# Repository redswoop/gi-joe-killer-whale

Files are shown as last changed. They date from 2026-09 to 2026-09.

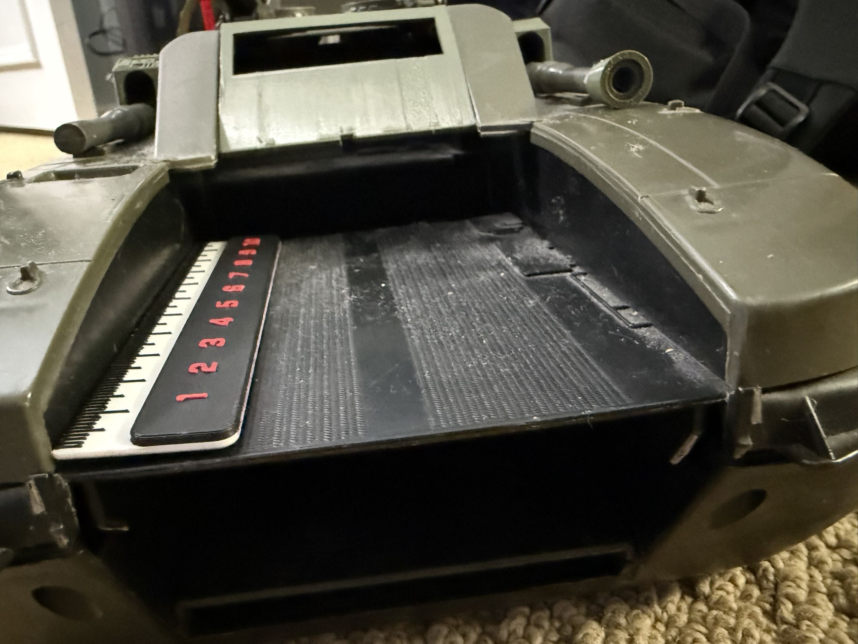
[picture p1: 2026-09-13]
hatch/ref/hull_photo_3.jpeg

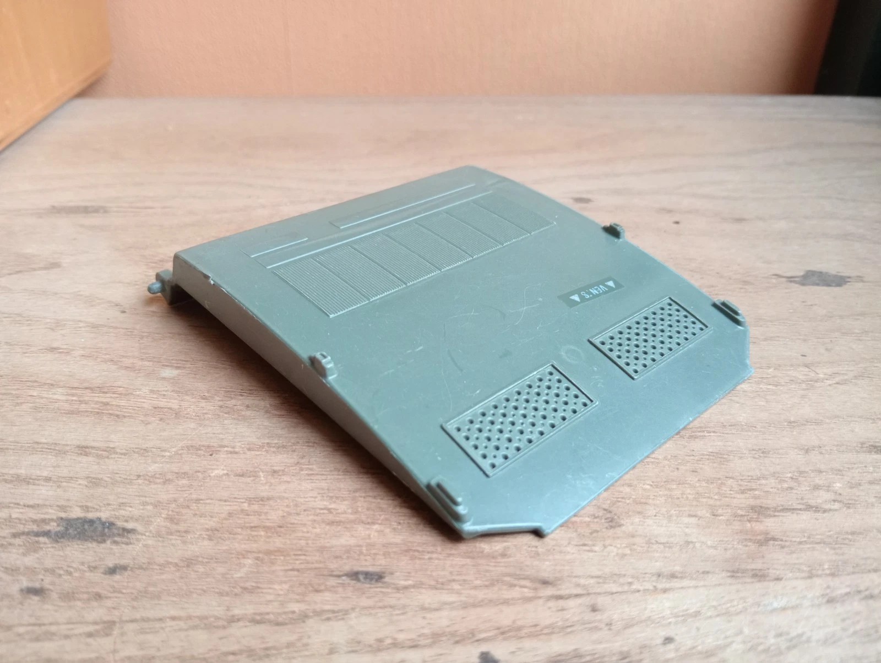
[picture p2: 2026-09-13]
hatch/ref/ebay_three_quarter.jpeg

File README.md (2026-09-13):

# Killer W.H.A.L.E. (1984 G.I. Joe hovercraft) replacement parts

Open-source (MIT) OpenSCAD replacement parts for the 1984 G.I. Joe Killer W.H.A.L.E. hovercraft.
On Makerworld: [cannon covers](https://makerworld.com/en/models/690907-gi-joe-killer-whale-cannon-covers); fan shroud listing in progress (`shroud/MAKERWORLD.md`).

## Building
Needs OpenSCAD 2025+ (Manifold backend). Shared helpers live in [`lib/`](lib/README.md) (a vendored copy of the
workbench's `scad/lib/`). Each assembly's `export.sh` regenerates its `stl/`; `print_layout.scad -D part="..."`
gives one part in its print pose; `check.scad` runs the collision pairs. Everything else below is workbench
convention (the viewer and `tools/` are not part of this repo).

## Layout
One folder for the whole toy, one subfolder per assembly. Each assembly has its own `.scad`,
`viewer.json`, coupons, checks, export script and README, so the viewer previews and rebuilds
them separately. The toy is one git repo (this folder).

| Assembly | Folder | State |
|---|---|---|
| Fan shroud + steering vanes | [`shroud/`](shroud/README.md) | Printed and fitted; fused shroud variant is current. |
| Front landing hatch (bow ramp) + hinge | [`hatch/`](hatch/README.md) | Three parts since 2026-09-13: tray with a dovetail socket, flat front plate with the pins, two glue-on brackets. Coupon (dovetail + pin fits) ready, nothing printed yet. Profile still the 3-point circle. |

Viewer: `cd ../viewer && bun run dev` (once), then http://127.0.0.1:5180/whale/shroud/ or
http://127.0.0.1:5180/whale/hatch/. Tools and shared modules are two levels up:
`use <../../lib/shape.scad>`, `../../tools/check.sh check.scad 'pose=..'`.

Reference material outside this repo: `../../WHALE/` (measurements, the small top-hatch 3mf),
`../../GI Joe/` (downloaded Thingiverse parts), `../GI_Joe_Killer_Whale_Blade.stl` (old fan mesh off the web).

Adding an assembly: `../tools/new-model.sh whale/<name>` copies the template into a new subfolder
(it does not run `git init` inside an existing repo).

History: `shroud/` was the `scad/whale/` repo until 2026-09-12; `hatch/` was a separate `scad/whale_hatch/`
repo, merged in with `git subtree add` so its commits are here too.

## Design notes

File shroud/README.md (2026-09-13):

# Killer W.H.A.L.E. fan shroud + steering vanes (OpenSCAD)

State as of 2026-09-12. Parametric port of Armen's Shapr3D shroud, plus a new print-in-place
vane mechanism reconstructed from photos of the real MET-b52 parts.

## Files
| File | What |
|---|---|
| `shroud.scad` | The whole model. Parameters at the top, one section per Shapr3D operation, then the vane mechanism. |
| `shroud_makerworld.scad` | **MakerWorld customizer build**: one self-contained file (lib inlined, `part` dropdown, curated parameters on top, the rest under `[Hidden]`), because the Parametric Model Maker takes a single file and runs OpenSCAD 2021.01. GENERATED by `build_makerworld.py` from `shroud.scad` + `print_layout.scad` + `../lib/`: re-run it after any change, then re-upload the file on MakerWorld. Verified 2026-09-13: every part renders with the same volume, area and bbox as `print_layout.scad` (zero voxel diff). |
| `viewer.json` | Part list for the browser viewer (`../../viewer`, `bun run dev`, open http://127.0.0.1:5180/whale/shroud/). |
| `print_layout.scad` | `-D part="..."`: each part in its printing pose. Vanes stand on their -Y end (`vane_pose = "vertical"`). With `-D 'vane_mount="fused"'`: `shroud` carries the root bars, `fin_right` / `fin_left` are the plates alone (`fin_print = "edge"`: upside down on the long outer edge, knuckles up; `"vertical"`: on the -Y end), `slat` has its axle barrel on the bed. |
| `hinge_coupon.scad` | Tolerance test print: hinge x3 (standing, pins vertical; `-D 'hinge_pin="filament"'` ladders the filament hole 0.10 / 0.15 / 0.20 instead), slat axle holes x3, keyhole eyes x3, strut pockets x3 + one ear, fork darts x3 (standing) + a piece of rim. |
| `saddle_coupon.scad` | Fit test for the saddle-mount alternative: three rim pieces with receivers at `chan_clrs` = 0.05 / 0.10 / 0.15, plus a standing stub of the bar's -Y end with the wedge peg. |
| `tab_coupon.scad` | Tab fit test print: four 108° arcs of the shroud (30 % of the ring, centred on the tab, `keep = 0.3`) with tab `variants` = [grip, stem_extra] pairs, labelled on a tag. Round 1 laddered the grip; round 2 ladders the stem width at grip 0.7. |
| `check.scad` | Collision pairs (`-D pair="..."`, `steer`, `tilt`, `strut_dz`), including `fan-duct`, `fan-strut`, `fan-roots`, `shaft-strut`. Run them all: `../../tools/check.sh check.scad 'steer=0' 'steer=30' 'steer=-30 tilt=20' 'strut_dz=8'`. Every argument is a pose, so the fused table is `'vane_mount="fused"' 'vane_mount="fused" steer=30' ...` (there `roots-duct` is skipped: one body by design). |
| `compare.scad` | Volume diff against the Shapr3D export (`ref_bodies/` = the STL split per shell). Numeric version: `../../tools/voxcmp.py stl/shroud.stl ref_bodies/shroud.stl`. |
| `export.sh` | Regenerates every STL in `stl/` in parallel. Plain names are the defaults; `_saddle`, `_filpin` and `_saddle_filpin` are the alternates, `_fused` is the fused variant (`shroud_fused`, `fin_right_fused`, `fin_left_fused`, `slat_fused`), plus `saddle_coupon.stl` and `hinge_coupon_filpin.stl`. Run after changing parameters. |
| `render.sh` | Headless PNGs into `renders/`. |
| `Shroud.shapr/.step/.stl` | Armen's originals. Read the .shapr with `../../tools/shapr_dump.py Shroud.shapr`. |

Generic helpers (`rounded_pad`, `wall_blend`, `arc_sweep`, `arc_pts`, `stroke_2d`, `grooves_2d`, `teardrop_2d`, `keyhole_2d`) moved to `../../lib/` on 2026-09-09; STL output was hash-identical before and after.

## Fixed 2026-09-13
`tooth_clr_eff` / `tooth_lead_eff` were assigned (in the fused block) before `tooth_clr` / `tooth_lead` existed, so in the
`teeth` variant the fork dart's slot clearance and lead chamfer were undef since 2026-09-12 (warnings "unknown variable
tooth_clr"). Moved after the tooth block; `export.sh` re-run. The re-exported teeth vane STLs have the same volume, area and
bbox as before (only the triangulation moved), so the undef never reached the printed geometry.
Note: `tie_bar.stl` is exported in `teeth` mode; in `fused` mode the hinge line (and with it the bar's pins) sits 0.2 higher,
which only translates the printed bar, so the file is the same shape either way.

## Coordinate frame
Z = duct axis (airflow exits +Z). Y = the toy's vertical, **+Y (tab side) = the toy's bottom**. X = port/starboard.

## Parts and how they go together
1. **Shroud** (`shroud.stl`, base down, no supports). Has: tooth notches in the rim for the vanes, pocket bosses in the bore at 3/9 o'clock for the strut.
2. **Strut / hub bar** (`strut.stl`, prints standing on one ear, brim, no supports). From the base side, line the ears up with the two pockets and push the bar in until the ears hit the pocket ceilings. The Whale's hull holds it there.
3. **Vanes** (`vane_right.stl`, `vane_left.stl`, standing on the -Y end, 99 mm tall, brim; the dart's underside may want a little support). Armen's call (2026-09-11): vertical prints the ribbed panels as wall detail and puts the hinge pins vertical. Print-in-place hinge: free each plate by working it back and forth. The +Y peg drops through the rim slot into the slot in the Whale's base; the -Y fork dart pushes down over the rim: key into the round notch, prongs straddling the wall, nub clicks.
4. **Slats** (`slat.stl` x2, flat). Spring the 59 mm rods into the holes in the two bars before the vanes go into the shroud. The plate now nearly spans the bars (0.3 mm end gaps), so they stay put sideways.
5. **Tie bar** (`tie_bar.stl`, knurl up). Bulbs go through the big keyholes, slide the bar aft, pins click into the working holes.
6. **Fan** (`fan.stl`, flat, no supports) and **shaft** (`shaft.stl`, lying on its D flat). Push the shaft's plain end into the
   blind D socket under the fan's hub; the tab end goes down through the strut's bore into the hull's push-button gearbox.

Print the **coupon** first and put the winning numbers into `hinge_clr`, `slat_clr`, `tooth_clr` (settled: 0.10, round 3, 2026-09-12), `tie_eye_clr`, `ear_clr`.

## Print next (as of 2026-09-12)
0. **Fan + shaft** (new, unprinted): `stl/fan.stl` (80 mm, flat) and `stl/shaft.stl` (75.5 mm, on its flat). Check the socket fit
   (`shaft_clr`), which way the gearbox turns (`blade_hand`), and how much longer the shaft must be (`shaft_extra`).
0. **Fused variant** (Armen's idea, 2026-09-12, see below): `stl/shroud_fused.stl` (now with the canoes; base down, 36 mm tall; the two bars bridge the bore
   about 20 mm up, so enable supports under them: support PLA, 0 interface distance, as the vane reprint used), `stl/fin_right_fused.stl` +
   `stl/fin_left_fused.stl` (standing on the long outer edge, knuckles up, no support), `stl/slat_fused.stl` x2 (flat), `stl/tie_bar.stl`, plus 2 x 15 mm and
   2 x 61 mm of 1.75 filament. Nothing of it has been printed yet.
0. Filament hinge settled (`fil_clr = 0.15`) and fork dart settled (`tooth_clr = 0.10`): the vanes can print now as
   `vane_right_filpin.stl` + `vane_left_filpin.stl` (fork mount), or `_saddle_filpin` if the saddle wins below.
0. `stl/saddle_coupon.stl` (103 x 39 mm, flat, no supports; the stub wants a brim): decide fork vs saddle. If saddle: put the
   winning cheek clearance into `chan_clr`, then print `shroud_saddle.stl` and `vane_*_saddle.stl` instead of the fork files.
1. `stl/hinge_coupon.stl` (89 x 109 mm): hinge 0.15 / 0.20 / 0.25, slat holes 0.10 / 0.15 / 0.20, fork teeth 0.10 / 0.15 / 0.20 on a piece of rim, strut ear pockets 0.10 / 0.20 / 0.30, keyhole eyes, bullet pins.
2. `stl/shroud.stl`: settled tab, strut pockets, and the new shallow (3 mm) key notches.
3. `stl/strut.stl` (ears in pockets, standing on an ear, brim) once the pocket clearance is known.
4. Vanes and slats once the coupon confirms `hinge_clr`, `tooth_clr` and `slat_clr`.

## Fan and shaft (2026-09-12)
Replaces `../../GI_Joe_Killer_Whale_Blade.stl`, an old mesh off the web that prints badly (thin twisted blades that are all
overhang, a 3.5 mm shaft 65 mm long printed on end). Measured from that mesh: 3 blades, tip r 42.6, blades about 5.7 mm
deep along the axis and pitched roughly 16 deg at mid-span with a straight radial edge and a curved swept edge, a 3.5 mm
shaft tapering to 2.7, and a 1.6 x 1.2 x 0.6 tab on its tip. Armen: the hull has a push-button spin mechanism with (he
thinks) a gear with a slot the tab goes into; the tab engages but the shaft is too short; it should be two parts so the
shaft can print horizontally.
- **Fan** (`fan()`, prints flat, hub bottom on the bed, no supports): hub `fan_hub_d` 10 x `fan_hub_h` 7 with a blind
  D socket `socket_depth` 5.5 deep from the bottom; `fan_n` 3 blades as lofted polyhedra (`blade()`). **Planform** (Armen: 'a smooth swoopy
  spline as their edge ... built between 2 smooth splines'): each edge is a cubic Bezier in a unit frame (1 = `fan_r`;
  `blade_te_c`, `blade_le_c` inner control points), both arriving at `blade_tip` along `blade_tip_dir` from opposite
  sides so the tip is a smooth round of size `blade_tip_k` (0.06: sharp and swept; 0.18 was a fat paddle). **Root**
  (Armen: 'they should end inside of the hub, with the edge fully in contact with the hub ... extrude from a projected
  profile on the hub'): both edges start ON the hub circle, +-`blade_root_a` about the blade's axis so the root chord
  (`blade_root_c` 0.15) is a chord of the hub, and that section is extruded straight inward `blade_bury` 1.5 before the
  Bezier stations begin; the root cap stays 2.5 from the axis, clear of the socket. **Section** (`blade_profile()`):
  flat bottom on the bed, a full round nose of diameter `blade_t` 1.0 at the leading edge, the top on a cosine from
  there up to the trailing edge's thickness, blade_t + chord x tan `blade_pitch` 12 deg capped at `blade_t_max` 2.2
  (the uncapped wedge hit 3.6 at the root: 'very fat, very stubby'; so the real slope is about 6 deg inboard and the
  full 12 outboard of mid-span), rounds `blade_r_top` 0.6 / `blade_r_bot` 0.3 on the trailing corners, all shrinking
  with the chord toward the tip. Nothing overhangs beyond the 0.3 bottom round and no edge is sharp. Lofted over
  `blade_nr` 40 stations to an apex at the tip. The console echoes the reach and the scale. `blade_hand` mirrors the blade once we know which way the gearbox turns.
  **Tip radius**: the strut's pocket bosses reach in to r 40.6, so the reference's 42.6 does not fit this shroud;
  `fan_r = boss_r_in - fan_tip_clr` = 37.6 (`fan_tip_clr` 3, Armen: 'end about 3mm from the mounting boxes'); the outline is scaled (`blade_S()`, a fixed point since the root sits on the hub circle) so its farthest point lands exactly there. The fan sits `fan_gap` 0.5 above the strut's hub core (`fan_z0` 3).
- **Shaft** (`shaft()`, prints lying on its flat): D section, `shaft_d` 3.5 (the reference's; the strut's bore is 5)
  with a `shaft_flat` 0.5 flat, which is the bed face and keys the torque into the hub's D socket (`shaft_clr` 0.10
  per side, untested). `shaft_len` = socket depth + `shaft_reach` 65 (the reference) + `shaft_extra` (0: Armen says
  the reference is too short, number TBD). **Gearbox end** (Armen got the gear out, 2026-09-12: 13-ish teeth, about 14 mm, a
  boss with a socket whose walls slope and whose floor has a keyed slot): the shaft's end is a BLADE that keys into the
  slot, `tab_w` 2.8 x `tab_t` 1.2 x `tab_len` 3.0 (guessed from the photos; **the first print fit the gear**, 2026-09-12; the mesh's
  1.6 x 1.2 x 0.6 pin was a guess), end corners rounded `tab_end_r`, and the shoulders where the round shank becomes the blade are
  convex rounded ramps `tab_ramp` 2.0 long in both directions, which seat on the socket's slopes ('the shaft should have
  rounded ramps to meet with the ramps in the socket'). Like a screwdriver tip ground from round bar; `shaft_tip()` is
  the intersection of the two side-view profiles, the shank cylinder and the D prism. Lying on the flat, the blade's
  underside is 0.65 off the bed for 3 mm: printable.
- Collision pairs `fan-duct`, `fan-strut`, `fan-roots`, `shaft-strut` all clear (teeth and fused, strut seated and
  pulled down 8). Renders: `renders/fan_iso.png`, `fan_top.png`, `fan_close.png`, `fan_hub.png`, `fan_asm.png`, `fan_on_strut.png`, `shaft_print.png`, `shaft_tip.png`, `shaft_tip_under.png`;
  `renders/fan_planforms.png` compares four outline candidates (A first spline, B scimitar, C paddle, D hook).
- Not modelled: any bearing between the hub and the strut (the reference had a 30 mm disc under the blades that may
  have ridden on the strut's ring), the gearbox end of the shaft beyond the tab.

## Fused variant: bars part of the shroud (2026-09-12)
`vane_mount = "fused"` (the default `"teeth"` is everything above; `-D 'vane_mount="fused"'` or the viewer panel).
Armen: "what if I just combined the shroud and the vane roots? That would give me a single, strong shape". So:
- **Root bars are part of the shroud.** Each bar stands on a `post()` at both wall crossings: the bar's own slab from
  `post_bury` (2) below the rim top up into the bar, trimmed to the wall's annulus at every height so it grows straight
  out of the wall with no overhang (the sketch pegs' boxes are longer than the oblique crossing and their corners
  would hang over the bore and past the outer face), with a `post_fillet` (1 mm) concave foot where the bar's faces
  meet the rim. No notches, teeth, receivers, pegs or darts: `vane_slots()`, `tooth_fork()`, `peg()`, `peg2()`,
  `receiver()` are all off. The +Y crossing keeps the same silhouette inside the wall as the sketch peg did in its notch.
- **Canoes on the fused shroud** (`fused_canoes = true`, 2026-09-12: "I don't see an STL with the fully composed shroud
  with the vane roots and canoes"): the posts stay the structure, and over them go the same fairings the loose vanes have:
  the -Y dart (`tooth_fork(-1)`), the +Y pod with its bore-side half-canoe (`peg_pod()`) and the +Y flare above the rim
  (`peg_flare()`, the peg's fillets without the peg's box, whose corners would hang over the bore). In fused mode the
  dart's slot clearance is `tooth_clr_eff = -0.2`, i.e. the prongs sink 0.2 into the wall, and the mouth chamfer is off:
  faces that only touch left the union with open edges and stray shells; sunk, `shroud_fused.stl` is one watertight shell.
  `-D fused_canoes=false` gives the bare posts.
- **Plates are separate parts** on the filament hinge (`hinge_pin` is forced to `"filament"` via `hinge_pin_eff`):
  drop the plate's middle knuckle between the root's two, push 15 mm of 1.75 through, trim 1 mm proud, mushroom.
  The root's holes print lying down in the shroud, so they are teardrops with the roof up (`fil_hole(roof = 1)`).
  **The plate prints standing on its long outer edge, upside down, knuckles up** (`fin_print = "edge"`; Armen's
  print experiments 2026-09-12: the best result of the poses tried), so its hole is a teardrop too, roof toward the
  hinge side (`roof = -1` in the model's frame). `print_layout.scad` levels the slanted edge (`fin_slant`, 6.5 deg)
  and drops it onto the bed. `fin_print = "vertical"` is the old on-end pose with a round hole.
- **Slats ride on filament axles** (`slat_axle()`, 61 mm): rigid bars cannot be sprung apart for a printed rod. The
  slat carries a barrel `slat_barrel_d` (3.45) on the axle, flush with its bed face and proud on the other, with a
  teardrop hole `slat_fil_clr` (0.10, untested; snugger than the bar's `fil_clr` so the slat stays where it is
  put). The bar's holes are `fil_d + 2 * fil_clr` teardrops. Push the filament in from outside the bar (open air
  above the rim), through the slat, out the other bar; mushroom both ends.
- **Print**: `shroud_fused.stl` base down as always. The bars float about 20 mm up and span the bore (70 mm between
  the posts, plus 10 mm cantilevers outside the wall): slicer supports under them. The root-to-rim joint is now in
  the layer-adhesion direction (a sideways push on a vane peels layers at the post), but the joint is the whole
  wall crossing (2 x 4.2 mm) plus the fillet foot, instead of 1.1 mm prongs. Plates print standing as before.
- **Checks**: fused collision table all clear at steer 0 / 30 / -30, tilt +-20, strut_dz 8 (`roots-duct` skipped;
  `slats-roots` includes the axles). `shroud_fused.stl` is one watertight shell (15.65 cm3). The `teeth` variant's STLs
  are unchanged in volume and area by the switch.
- Untested: everything. Bridging / support removal under the bars, `slat_fil_clr`, how the posts look on the toy, and
  whether the Whale's base slot still meets the +Y crossing the way it met the peg.

## Hinge pin: printed or filament (2026-09-12)
`hinge_pin = "printed"` (default, the print-in-place pin) or `"filament"`. **Why**: the vertical vane print
(2026-09-11) came out beautifully, then the hinges snapped as soon as the plates were freed. Standing, the 1.4 mm pin
is printed along its axis: a stack of discs held by layer adhesion, sheared by the first twist. **Filament**: the
knuckles get a plain round hole (`fil_d` 1.75 + 2 x `fil_clr` 0.15 = 2.05) straight through the nub and out both
ends, the barrel grows to `barrel_fil_d` 4.6 for 1.28 mm walls (the hinge line rises 0.2 with it; collision table
still all clear, with either mount), and the teardrop is gone since the vertical holes print round. Root and plate
still print together in place, knuckles aligned. **Assembly**: cut 15 mm of 1.75 filament per nub (`hinge_len` 12.8 +
2 x `fil_proud`), push it through, trim 1 mm proud each end, mushroom the ends with a lighter or soldering iron. No
freeing step, and `hinge_clr` no longer matters. `fil_clr = 0.15` confirmed on the filament coupon (2026-09-12: 0.10 / 0.15 / 0.20
printed, 0.15 best). Untested: how a mushroomed end looks on the inside face. Renders: `renders/filpin_hinge.png`, `filpin_end.png`, `filpin_coupon.png`.

## -Y mount: two variants side by side (2026-09-11)
`ny_mount = "fork"` (default, the current design) or `"saddle"` (the alternative). Flip it in the viewer's parameter
panel to compare; on the CLI `-D 'ny_mount="saddle"'`. The fork variant's STLs are geometrically unchanged by the
switch (same volume and area, zero `voxcmp` difference against the pre-switch export).

**Why**: the fork darts (1.1 mm prongs on the vane, printed standing, with support) broke off during support removal.
**Saddle**: the shroud grabs the vane instead. `receiver()` is a block on the rim at each -Y crossing, aligned with
the bar and trimmed to r `recv_r_in` 41 .. `recv_r_out` 48, printed flat with the shroud so its layers run along its
loads. `channel_cut()` runs the bar's tapered slab (grown `chan_clr`) through it from `chan_clr` under the bar's
bottom line up: two 1.6 mm cheeks up to `recv_z_top` (24.5, half a millimetre under the slat rod) grip the bar's faces
and stop it rocking; the mouth has a 0.6 mm lead-in. Below the bar, `peg2_pocket()` takes the sketch's own -Y peg
(`peg2()`: y -38.44 .. -31.66, bottom z 14.71) with its -Y face sloped 45° (`peg2_slope`), so the standing vane prints
it without support and it self-centres along the rim on the way in; the pocket's +Y wall and floor locate the vane.
A nub on the inner (fan-side) cheek at `recv_nub_z` clicks into a dimple in the bar; the cheek, backed by the boss
below the rim, is the flexing member (interference = `recv_nub_h` - `chan_clr` = 0.15). Below the rim the block fades
into both faces of the wall with 2 mm concave fillets (`recv_plan_2d`, the strut boss's offset trick) and stands on
45° chamfers: `recv_ok_in()` inside the bore from `recv_z_low` 12, `recv_ok_out()` outside from just under the rim,
2.4 mm above the deco boxes. Top edges rounded `recv_top_r`. Both cheeks exist only where the bar is inside the
annulus (the outer one for the +Y 6 mm of the block, the inner for the -Y 8 mm; both over the middle 3.6 mm).
Collision table all clear at steer 0 / 30 / -30+tilt 20 / tilt -20 / strut_dz 8. The +Y peg and its base slot are
untouched. Renders: `renders/saddle_receiver.png`, `saddle_vane_in.png`, `saddle_bore.png`, `saddle_peg.png`,
`saddle_coupon.png`, `saddle_asm_iso.png`. Untested: `chan_clr` (coupon), the nub's click, how the block reads on the toy.

## Design notes
- Hinge (printed pin): two 13 mm nubs per vane at y = -34 / 36 (over the teeth), barrel 4.2, round pin 1.4, teardrop holes, barrels on the inside face. Printed vanes at `hinge_clr = 0.4` swung through the full range but were too loose (2026-09-10); Armen's own tolerance tests say 0.15 (2026-09-11) -> `hinge_clr = 0.15`. **Confirmed 2026-09-11 on a full vane printed at 45° with the pins near vertical: "perfect, almost feels oiled".** (Coupon round 1 called 0.25 stuck, but that was printed flat with horizontal pins; the number depends on the pin being vertical.) `hinge_lift = 0.6` keeps the barrel off the bar's top edge (a printed barrel has a flat where it met the bed).
- **Teeth** (2026-09-11). The two ends of each bar differ:
  - **+Y (toy's bottom): the original Sketch 06 peg**, `peg()`: the bar's thickness, 5.27 wide (y 31.9..37.2), 2.2 mm below the rim (z 19.065), sharp-edged, no nub. It drops through the rim slot into a small slot in the Whale's base, so from the rim down it keeps the sketch's size exactly ("the slot is quite small, 1-2 mm depth max"). The rim slot is the peg + `peg_clr`. **Root flared (2026-09-12)**: the first printed vane snapped off at this root (sharp inside corner on a 2 x 5.27 section). `peg_2d()` now flares the peg into the bar's bottom edge with `peg_fillet = 3` concave fillets on both sides, in the bar's plane, using 3 of the 4 mm between the bar's edge and the rim top (they stop ~1 mm above the rim, so the notch and the base slot see the plain peg). Extruded at the full 2 mm, so it stands 0.06 proud of the tapered bar over that strip. **Canoe (2026-09-12)**: `peg_pod()` wraps the root in a body of revolution on the bar's mid-plane, `peg_pod_r = 2.75` (just over the peg's half-width), full round to `tooth_over` past the bar's edge, cone tail `peg_pod_tail = 5` fading into the bar (added after the panel grooves are cut, so it rides smoothly over the ribbed panel). Below `peg_pod_clr = 0.5` above the rim, only the part inside the bore survives: a half-canoe hugging the bore wall (r < 44 - `tooth_clr`) with an ogive nose `peg_pod_nose = 6`, tip `peg_pod_prong = 8` below the rim, so the root also grips the inside of the wall like the dart's inner prong. Outside the bore nothing reaches below the rim: the rim notch and the base's slot see only the plain peg. Renders: `renders/peg.png`, `renders/peg_iso.png`, `renders/peg_bore.png`.
  - **-Y (toy's top): a fork dart**, `tooth_fork(-1)`: a slender body of revolution about an axis along Z on the bar's mid-plane, so it is the same on both faces. Tangent-ogive nose `tooth_nose = 8` reaching `tooth_prong = 11` below the rim (tip near the shroud's mid-height), cylinder `tooth_r = 2.25` through the rim (3 was "far too fat") and on past the bar's bottom edge by `tooth_over = 1.5`, so the pod straddles the edge at full width (the cone used to meet the edge at a point, "feels like a failure point"), then cone tail `tooth_tail = 6.5` fading up the bar's face; it runs into the slat hole, where it is only a hair proud of the bar. The wall's annulus (offset `tooth_clr`) splits it into two D prongs 3.9 wide and 1.1 thick that grip the wall; the key drops `tooth_key = 3` into a round bite in the rim whose curved end walls locate it along the rim; a nub on the key clicks into a dimple. At the mid-plane the pod sits 50.7° around the ring, and its outer prong reaches down beside the deco box at 45°: `deco_box_keepout()` shaves a small flat off that side (`tooth_box_clr = 0.3` from the box and its blend), below the rim, among the boxes. History: flat dart with fillets (49ceeaa, "ugly"), fat canoe pod clipped flat on the outer face (506b449, "looks weird"), then this.
- **Taper** (2026-09-11, "the slightest taper, widest at the root where they attach to the duct, down to a thin edge at the outside"): both plates thin linearly with z from `vane_t = 2` at the bar's lowest edge (z 20.6) to `vane_t_tip = 1.2` at the plate's farthest corner (z 59.2), symmetric about the mid-plane (`vane_thk(z)`, `thk_wedge()`); each face slopes 0.6°. So the bar runs 2.0 -> 1.8 and the plate 1.7 -> 1.2. The panel grooves are cut from the sloping face (`face_cut` uses `outer_beyond`) so they keep their 0.4 depth. The link pin moved to the mid-plane (`pin_x`); its mount wraps the thin corner on both faces, so it stays rooted (see the tie bar note). The +Y peg keeps its full 2 mm (it is 0.06 proud of the bar at its top, invisible). Section: `renders/vane_taper_section.png`; pin: `renders/pin_corner.png`.
- **Rounded edges** (2026-09-11, "they look too blocky"): `plate_yz()` builds each plate as the outline shrunk by r, extruded, cut to the tapered wedge pulled in by r, then minkowski'd with a sphere (the `rounded_plate()` recipe from `../../lib/shape.scad` with the wedge in the middle). `vane_edge_r = 0.5` (0.7 before the taper; the 1.2 mm tip needs r <= 0.6) on every edge of both faces; convex outline corners come out rounded too. The +Y peg is deliberately not rounded. The plate's two inner corners (along the hinge, next to the bar's square end corners) are square in plan to match it; the two outer corners keep `fin_corner = 2`. Standing vertically, the end faces on the bed are ~1.4 mm wide at the first layer: brim. The hinge webs, knuckle ends, tie bar and slats are still sharp-edged. Render: `renders/vane_edges.png`.
- **Plate span**: `hinge_y0` is now the bar's -Y end (-45.72, was -44) so the plate stands on the bed with the bar when printing vertically.
- Slats: `slat_clr = 0.15` (0.2 printed loose), and the plate spans the bars less `slat_end_gap = 0.3` per side (54.4 at the rod) instead of the 52 mm photo estimate, so a slat cannot shuffle sideways.
- Linkage is a four-bar, solved in `solve_left()`; ~0.8° asymmetry at 30°.
- The tie bar is the hat-shaped `_/----\_` original with a knurled middle. Its raised middle's outer edge is flush with the plates' outer edge at rest (`tie_jog = link_pin_inset - tie_w / 2`, 4.3), per Armen 2026-09-11.
- **Link pin mounts** (2026-09-11, "these should also canoe up the vane; move them about 3 mm from the edge"): `link_pin_inset = 5.8` (was 2.8), so the mount sits 3.5 mm inside the plate's outer edge. The root is a canoe about the pin's axis on the plate's mid-plane, `mount_d = 4.5` like the tooth: a cone tail `mount_tail = 6` fading up the plate (-Y), a cylinder `mount_cyl = 2` to the plate's end, a nose cone down to the pin ending `mount_nose` (tie_gap - 0.3) past the end so the eye seats on the pin, then the pin and its bulb. Renders: `renders/pin_corner.png`, `renders/tie_flush.png`, `renders/tie_closeup.png`.
- Strut mount v4 (2026-09-10): **ears in pockets**. The bar's ends turn up into 2 mm curved ears hugging the bore wall, half the shroud's height (`ear_top = 9.5`). A boss on the wall at each end (13.7 wide, 3.4 proud, 11.2 tall, fading into the wall with 3 mm concave fillets on its sides and top: `boss_fade`, built with the `offset(r = -f) offset(r = f)` trick) holds a pocket open at the base and blind at the top, with a notch through its inner lip for the plate. Insert from the base side. `ear_clr = 0.2` per face, untested. Bar plane back at z = 0 as in the Shapr3D original. Earlier ideas in git history: v3 twist lock (be6d171), dovetail slides (9d956e5).
- Slats never reach the hinge line thanks to their taper; the plates first touch a slat at 40° steer.
- `print_face = "inner"` flips the vane to print barrels-down with support PLA, putting the ribbed panels on top.

## Open items
- All plate/slat/pin dimensions are photo estimates scaled off the 92 mm bar; calipers on the real parts would firm them up. Also unmeasured: the slot in the Whale's base that the +Y peg drops into (assumed to fit the sketch peg).
- Vane print 2026-09-11 (Armen, 45°, forks toward the bed): hinge perfect; **the fork darts broke off during support removal** (1.1 mm prongs). Second print lying on its side, hinges down, support PLA with 0 interface distance: **the root then snapped off the duct at the +Y peg** (2026-09-12) -> peg root flared with 3 mm fillets, unprinted. Armen wants the bottom mount "more beefy" and keeps the canoes at the top; if the fillets are not enough, the 4 mm of clearance above the rim allows a taller shoulder (`peg_fillet` up to ~3.5) before the bar itself would have to move.
- Fork darts: too fragile for support removal at `tooth_r = 2.25`. Options on the table: fatter pod (r 2.6 gives 1.5 mm prongs), shorter dart, a teardrop section that prints self-supporting standing up, or a sacrificial bridge across the prong tips. **Or the saddle variant above (`ny_mount = "saddle"`), which has no thin features on the vane at all.**
- Coupon round 3 not yet printed: hinge 0.15 / 0.20 / 0.25, slat holes, fork teeth 0.10 / 0.15 / 0.20, ear-in-pocket fit (0.10 / 0.20 / 0.30), keyhole click, bullet-rooted pins.
- Fallback if the keyhole/pins still misbehave: a separate reinforced peg that tabs into a slot in the plate.
- Mounting tab: settled by two coupon rounds on 2026-09-10 (olive green). Round 1 grip 0.8 best but a tad tight, 0.5 loose -> `tab_grip = 0.7`. Round 2 stem width: +0.15 and +0.3 both good, +0.3 a tad much -> `tab_stem_extra = 0.2`. Not yet tested on a full shroud print.
- Fan and shaft (2026-09-12): unprinted. Blade fits the gear (printed 2026-09-12). Open: `blade_hand` (gearbox direction), `shaft_extra` (how much longer), `shaft_clr`
  (socket fit), whether the blades want more pitch or a thinner section (a thin twisted plate would need support or an
  on-edge print). The spin box itself is still out of scope.
- Fused variant (2026-09-12): unprinted. See its section above for what to watch.

## Gotchas learned
- This OpenSCAD nightly renders a small-angle `rotate_extrude` as a single chord; `arc_sweep()` hulls per-degree slabs instead.
- Bun.serve drops idle connections after 10 s: the viewer server sets `idleTimeout: 0` and heartbeats.

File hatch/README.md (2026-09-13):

# Killer W.H.A.L.E. front landing hatch (bow ramp) with replacement hinge

State as of 2026-09-13 (evening). Three printed parts: the arched tray (`hatch`) with a dovetail socket under its front edge, a flat front plate (`front`) that slides into it along X and carries the hinge pins out of its side edges, and two brackets (`mount`) with pin holes that glue to the fenders. Coupon for the dovetail and pin fits is ready and unprinted. Pin position and bracket size are estimates.

## What the part is
The bow ramp of the 1984 Killer W.H.A.L.E. (part "landing ramp" / "sled launch ramp door"). A large curved plate
that closes the bow opening, hinged along its bottom edge, folding forward and down to lie as a ramp
(treaded face inside). Armen's example is missing the hatch entirely (2026-09-11), so the plate is designed from the hull:
its side-edge profile is traced off the fenders' inner top edges, which the closed ramp sits flush with.

## Reference material found (2026-09-11)
- `../../../WHALE/measurements.md`: ramp width 93.3 mm. That is the only ramp number on disk.
- `../../../GI Joe/GI Joe Killer WHALE Landing Ramp Hinge Replacements - 4094032.zip` (Cryoguns, Thingiverse
  thing:4094032, CC BY-NC): a pair of glue-on hinge brackets for this exact ramp. Summary: "One of the worst
  [breakages] was breaking the front landing ramp hinge pins"; cut the original hinge remnants out with a
  razor saw and glue these in. Bracket 21.4 x 8.1 x 11.1 mm, two uprights with a **3.10 mm pin hole**,
  axis 4.55 mm above the bracket's base, plus a triangular gusset. Renders in `renders/` once render.sh runs.
- Not the ramp: `../../../WHALE/Whale Hatch.3mf` (55 x 72 x 6.2 mm) is the small TOP hatch, and thing:6660330
  "Hatch Hinge" is that top hatch's pin.
- `ref/`: Armen's pencil tracing of the fender edge (`profile_tracing.jpeg`: 28 / 24 / 10 above the paper edge at
  0 / 50 / 90), his five hull photos (`hull_photo_*.jpeg`) and the eBay photos of the real ramp (`ebay_*`).
  Recovered from the 2026-09-11 session transcript on 2026-09-12.

## Files
| File | What |
|---|---|
| `whale_hatch.scad` | The model: `hatch()`, `front()`, `mounts()`, `bay_mock()`. |
| `viewer.json` | Part list for the browser viewer (`../../viewer`, `bun run dev`, open http://127.0.0.1:5180/whale/hatch/). |
| `print_layout.scad` | `-D part="..."`: each part in its printing pose. |
| `check.scad` | Collision pairs; `../../tools/check.sh check.scad 'pose=..'`. Empty = clear. |
| `coupon.scad` | Tolerance test print. |
| `export.sh` / `render.sh` | STLs into `stl/`, PNGs into `renders/`. |
| `ref/` | The tracing, hull photos and eBay photos; captions and the tracing's pixel scale in `ref/index.json`. Shown in the viewer's gallery. |
| `annotations.json` | Viewer notes and the overlay placement. `../../tools/notes whale/hatch` lists them. |

## Coordinate frame
Hinge axis = X at the origin, +Y aft toward the cabin, +Z up. The plate is modelled closed, in a "plate frame"
whose origin is the outer surface's front corner (top of the front face); the arc runs to (hatch_len, hatch_rise)
arching hatch_sag above that chord. `hatch_shift` (computed) moves the plate so the pin axis lands on X; the
console echoes where the axis sits relative to the front face and the lip level. `open_deg` swings it down over the nose.

## What the 2026-09-11 photos showed (Armen's hull, ruler in cm)
- The bay is an open-topped box between two fenders, cabin at the back, black treaded floor. The closed ramp
  is a shallow arched lid over it, flush with the fenders' curved top edges, hinged at the front lip;
  lowered, it folds forward over the nose to the ground.
- Bay width at the cabin end ~100.5 (ruler across); lip to the fender corner at the cabin ~102 (ruler along).
  Ramp width 93.3 (measurements.md) leaves ~3.5 per side for the side rails / channel seen along the floor edges.
- The round "nub" at each front fender corner is a fender rivet: the same ring-and-stub repeats all over both
  fenders. Not a hinge remnant. The hull-side hinge points are still unidentified.
- Left side of the bay has a black channel with slots along the floor edge; right side a rail with three
  rectangular notches. Purpose unknown (sled guide? ramp latch?).

## Settled 2026-09-11
- Profile: Armen traced the fender edge on paper: drops 0 / 4 / 18 below the baseline at 0 / 50 / 90 mm.
  Circle through those: R 180.7, chord 91.8, sagitta 5.9 -> `hatch_len 90, hatch_rise 18, hatch_sag 5.9`.
  The steep end is the hinge (front lip), the flat end sits at the cabin.
- Thickness 1.5 (`hatch_t`), "same as the rest of the shell". A 93 x 92 plate at 1.5 will flex; ribs on the
  inside face (the original had tread there) are the fix if it does.

## Needed from Armen
1. Hull side: the pin holes in the fenders' inner faces at the front lip: diameter, height above the floor,
   distance behind the lip. These set `pin_drop`, `pin_back` and `hinge_pin_d`.
2. After the first print: where it stands proud or falls short, and by how much.

## What the real part looks like (eBay photos, 2026-09-11)
- A shallow tray: the plate with a ~3 mm rim on the inside along both sides and the cabin end. A separate
  black treaded "liner" (two tread strips, side clips) snaps into the tray. Mold number M-3798-4.
- Hinge: a round bar across the whole hinge edge on the inside, lobed ears at both ends, short pins (~2.6 dia,
  ~3.5-4.5 long) pointing outward into holes in the fenders. Width 93.3 + 2 x 3.5 pins = 100.3, which matches
  the ~100.5 measured between the fenders.
- Cabin end: square edge with 45 deg corner cuts in plan bringing the edge to `top_edge_w 68.85`, the wide
  end of the top-hatch opening. A ledge (`lip_drop 2.7` below the outer surface, `lip_t 1.5`, `lip_len 5`)
  tucks under Armen's 2.5 top hatch; it is the step visible on the inside of the real part. The plate
  scales to ~97 long on the photo vs the 90 traced lip-to-cabin, which is that ledge.
- Four small latch hooks on the side edges (two per side, ~14 % and ~48 % of the length from the cabin end),
  engaging the notched rails on the fenders. Not modelled yet.
- Outer face: two perforated vent grilles near the cabin end, seven ribbed panels, "PANEL REMOVAL" /
  "UNLATCH" / "RAMP ACCESS" labels. Cosmetic, not modelled yet.

## Hinge end (Armen 2026-09-13): the front is its own part, dovetailed to the plate
Armen: "the entire front and hinge assembly should dovetail to the top ... then the front we can iterate on.
The front should be flat, with the joints coming out the sides", plus a mount for the pins that sits outside
the front and fixes inside the hull.

- **Socket** (`hatch`): a block under the plate's front edge, `sock_d 5.15` deep, from the outer surface down
  `sock_h 4.5` (= skin + rim, so the seam is level with the rim's underside). A dovetail groove runs the full
  width, open at both ends, mouth on the seam face. The block's front face is the top 4.5 of the vertical
  front drop. It is clipped against the outer arc only (`band_2d` would cut it along the slanted radial
  line at the plate's front corner and shave the groove's lip off; that bug is fixed).
- **Front** (`front`): a flat plate `front_t 3.5` thick, `hatch_w` wide, from the seam down to
  `pin_edge 2.5` below the pin axis (11 tall). Its top edge carries the rail: `rail_h 1.2` up, `rail_neck 1.2`
  thick where it leaves the plate, widening by `rail_taper 1.0` toward the OUTER face. One-sided dovetail: the
  inner face is flat so the front prints on that face with no overhang and the taper is a top-side slope.
  Pins `hinge_pin_d 2.6` x `pin_len 3.5` straight out of the side edges, axis `pin_y` = 2.2 aft of the outer
  face (so they lie on the bed) and `pin_below_lip 3` below the lip level (PHOTO ESTIMATE; the hull decides).
  `rail_2d(g)` gives the profile, grown by `g` for the groove (`slide_clr 0.15` per face, coupon).
- **Mounts** (`mounts`, print `mount.stl` twice): a `mount_len 14` x `mount_h 10` x `mount_t 3.0` plate with a
  `hinge_pin_d + pin_clr 0.4` hole `mount_hole_back 5` from its front edge and `mount_hole_up 4` above its
  bottom, corners `mount_r 1.5`. `mount_t` is the fender gap ((100.5 - 93.3) / 2 = 3.6) minus a hair, so the
  3.5 pin passes through; `mount_clr 0.2` off the front's side edge. Glue face = the outer face.
- **Assembly**: slide the front into the socket from one side (the brackets stop it sliding back out), put a
  bracket on each pin, set the hatch closed and flush in the bay, glue the brackets to the fenders' inner
  faces with the hatch as the jig. No hull holes needed; the pins never touch the hull.
- The angled skirt and the tilted slide bar from earlier on 2026-09-13 are gone (git history has them). The
  front plate is the place to bring an overhang back if the hull wants it.
- `check.scad`: `hatch-front`, `front-mounts`, `hatch-mounts` all clear at 0 and 115 deg.

## Print next (as of 2026-09-13)
1. `stl/coupon.stl` first: three 20 mm socket slices (groove at 0.1 / 0.15 / 0.25 per face, standing so the
   slot is vertical like the real hatch) + one 20 mm rail slice printed on its inner face; three pin holes
   (+0.3 / 0.4 / 0.5) + a pin stub. Report which slide is snug-but-moving and which hole turns freely;
   write back `slide_clr` and `pin_clr`.
2. `stl/hatch.stl` ON ITS SIDE: the +X side face on the bed, footprint 22.8 x 94.8, 93.3 tall. Brim. Arc,
   front face and groove are traced in every layer.
3. `stl/front.stl` flat on its inner face, 100.3 x 12.2 x 3.5, pins lying on the bed.
4. `stl/mount.stl` x2, flat, 14 x 10 x 3.
- Fit checks: curve flush with the fender edges and the front face flush with their 10 mm front drop; the
  front slides in and stays; brackets fit the fender gap (`mount_t`); the pin height that lets the ramp open
  over the lip (`pin_below_lip`); cabin end under the top hatch (`plate_extra`, `lip_len`); width between
  the rails.

## Tracing overlay (2026-09-12)
`profile_tracing.jpeg` is placed in the viewer as overlay `o1`: plane YZ (the plate runs along +Y, Z up), calibrated
on the 50 and 90 mm ticks (0.0613 mm/px), flipped horizontally so the hinge end is at y = 0, origin at the curve's
hinge end (px 1438, 1257). Side view + Ortho shows the pencil line over the model's edge; they agree to within the
pencil width on a first look. The 0 mm tick is just off the left of the photo, so the cabin end of the curve is not
in frame.

## Open items
- Everything above. Coupon not yet printed.
- Hull side: how far below the lip the axis must sit for the front plate to swing clear of the lip's front
  face (`pin_below_lip`), and whether the bracket's 14 x 10 footprint has a flat fender face to glue to at
  that spot. No lip in `bay_mock` yet.
- The front plate is flat; the real part's angled skirt / overhang could return as a feature of `front`.
- Trace the fender edge properly: `k` (points tool) along the pencil line on overlay `o1`, Enter, then
  `../../tools/notes whale/hatch points <id> --scad fender_pts --2d` gives a `[y, z]` list. The single circle
  (`hatch_sag`) sits a little low mid-span and a little high at the hinge; a polyline or two-arc profile through the
  traced points would replace it.

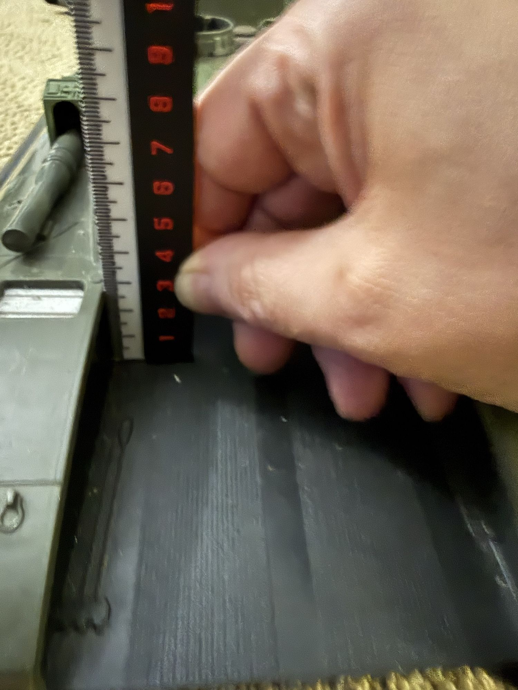
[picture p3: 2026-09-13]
hatch/ref/hull_photo_2.jpeg

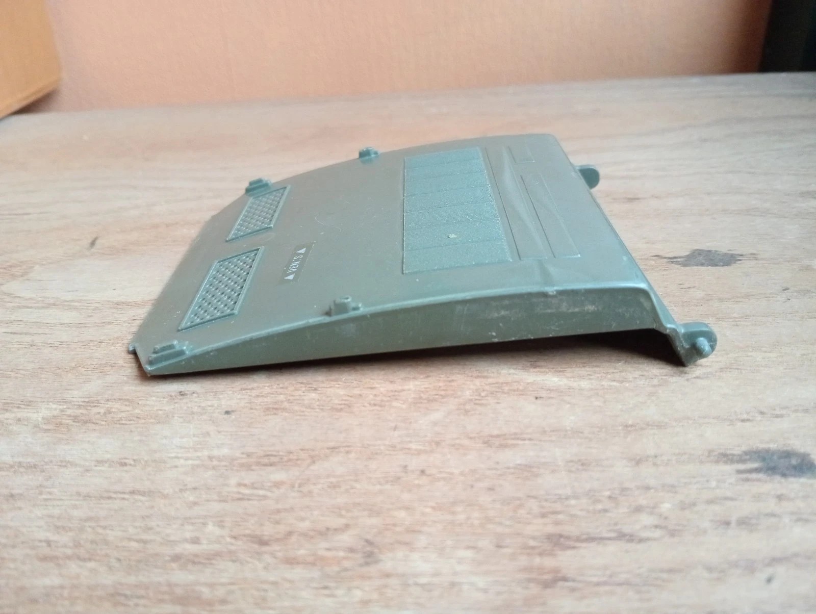
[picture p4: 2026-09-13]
hatch/ref/ebay_edge_profile.jpeg

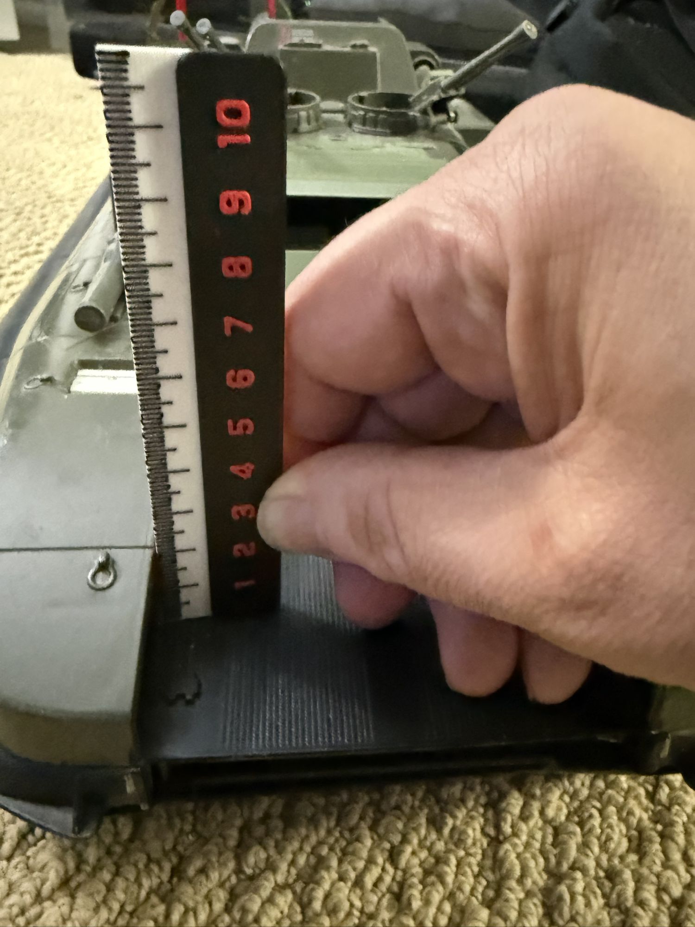
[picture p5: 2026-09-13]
hatch/ref/hull_photo_1.jpeg

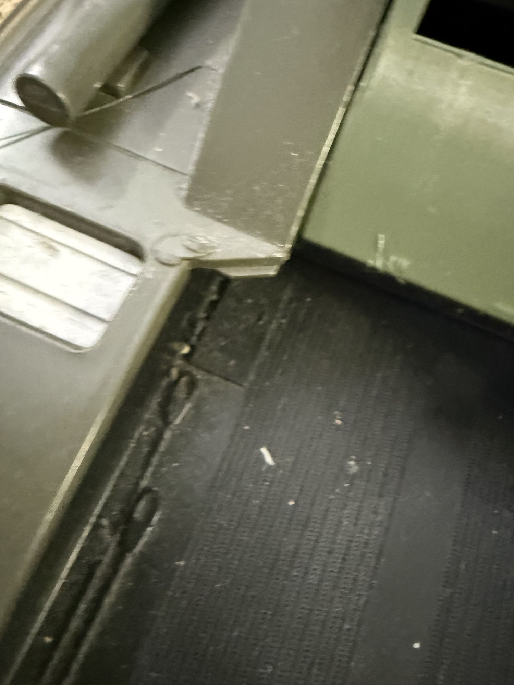
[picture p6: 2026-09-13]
hatch/ref/hull_photo_0.jpeg

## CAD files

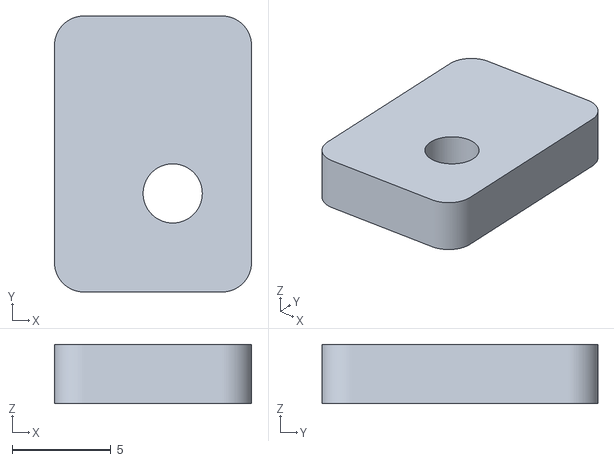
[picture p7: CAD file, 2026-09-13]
hatch/stl/mount.stl
10.0 x 14.0 x 3.00

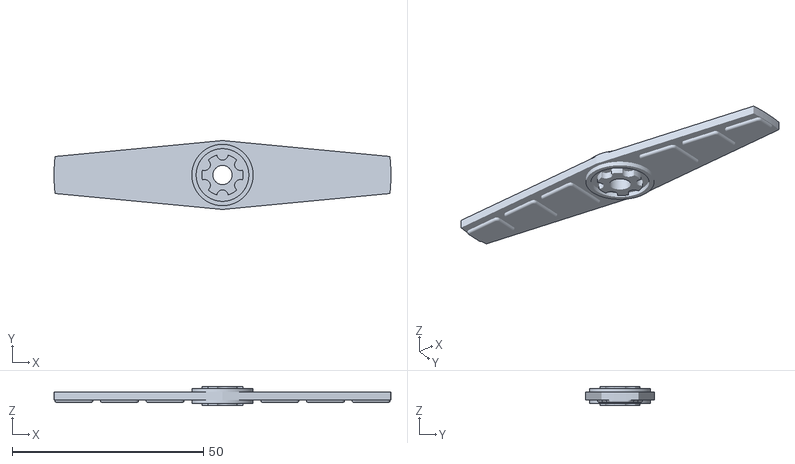
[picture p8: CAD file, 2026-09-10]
shroud/ref_bodies/strut.stl
88.0 x 18.0 x 5.00

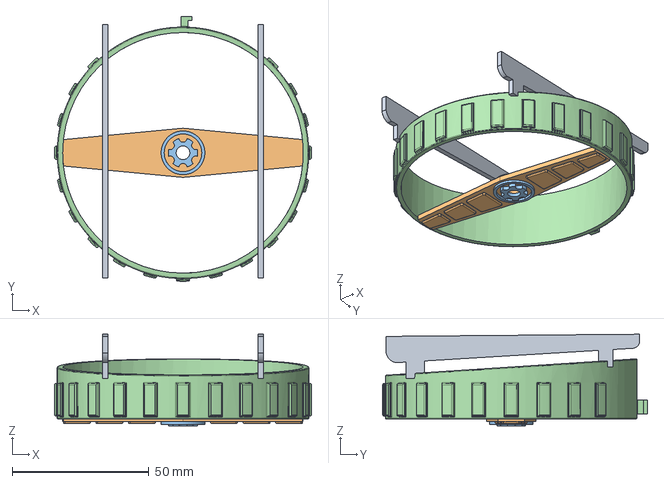
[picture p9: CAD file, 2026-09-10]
shroud/Shroud.step
94.0 x 96.8 x 33.5 mm

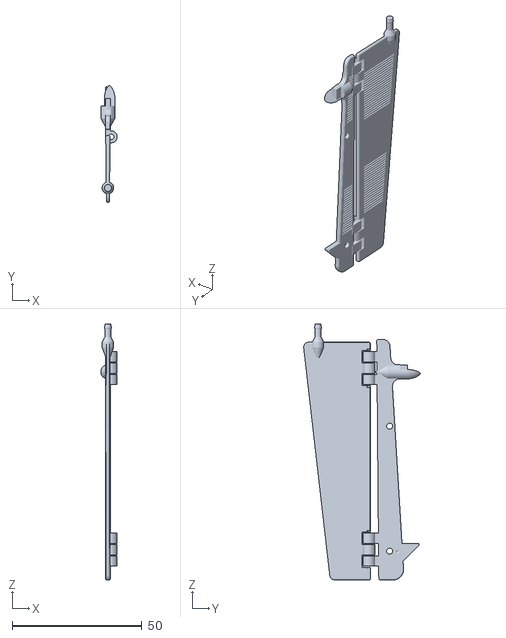
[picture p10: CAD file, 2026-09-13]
shroud/stl/vane_left_saddle_filpin.stl
6.35 x 45.0 x 98.7

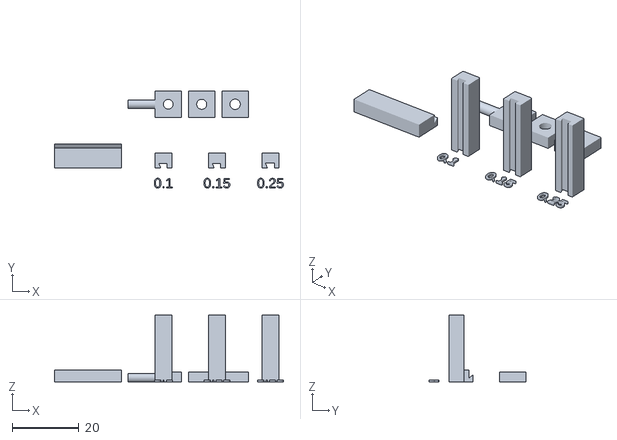
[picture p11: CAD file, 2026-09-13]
hatch/stl/coupon.stl
68.5 x 29.0 x 20.0

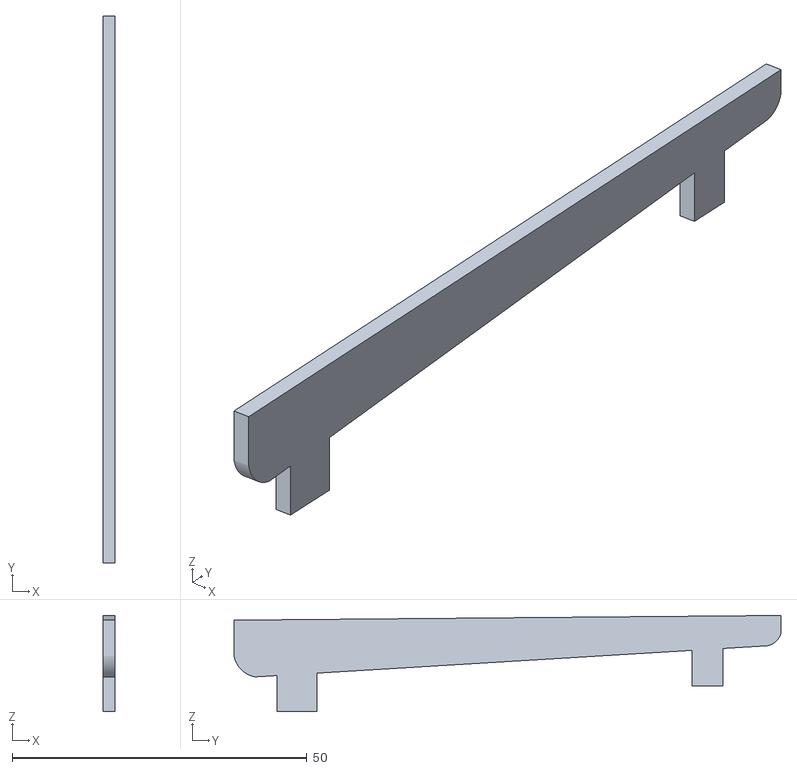
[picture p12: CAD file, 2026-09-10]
shroud/ref_bodies/vane_left.stl
2.00 x 92.7 x 16.3

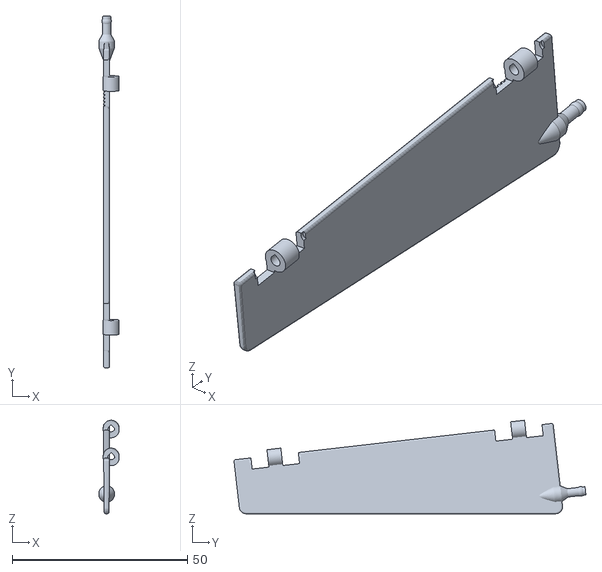
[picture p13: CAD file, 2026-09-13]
shroud/stl/fin_right_fused.stl
5.85 x 100.5 x 26.7

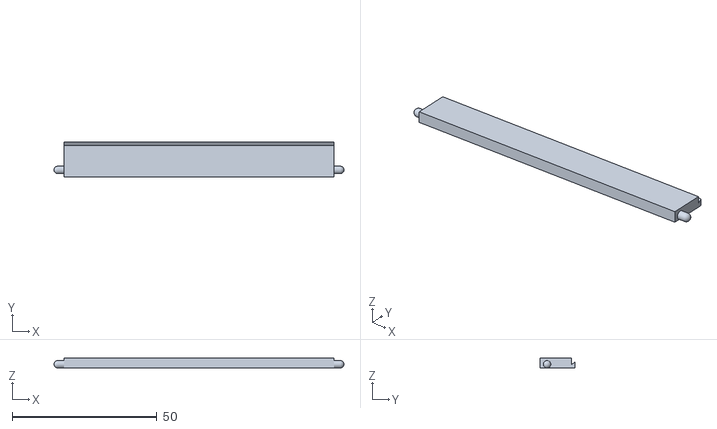
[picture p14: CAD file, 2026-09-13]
hatch/stl/front.stl
100.3 x 12.2 x 3.50

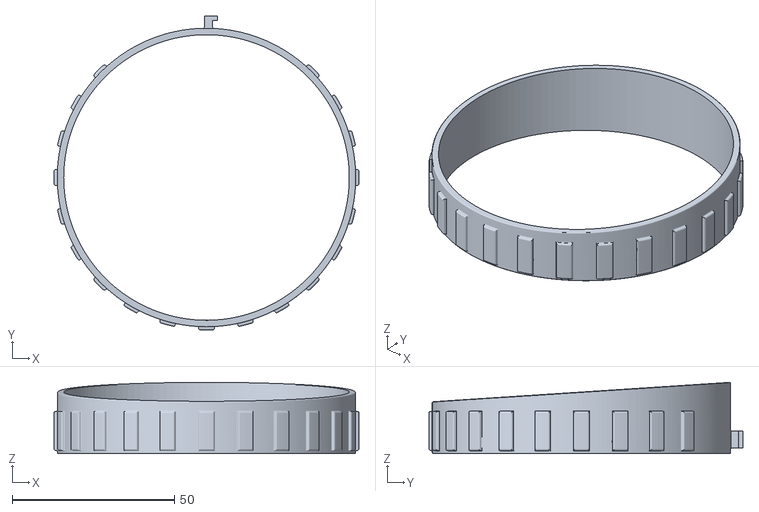
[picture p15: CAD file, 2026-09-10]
shroud/ref_bodies/shroud.stl
94.0 x 96.8 x 22.0

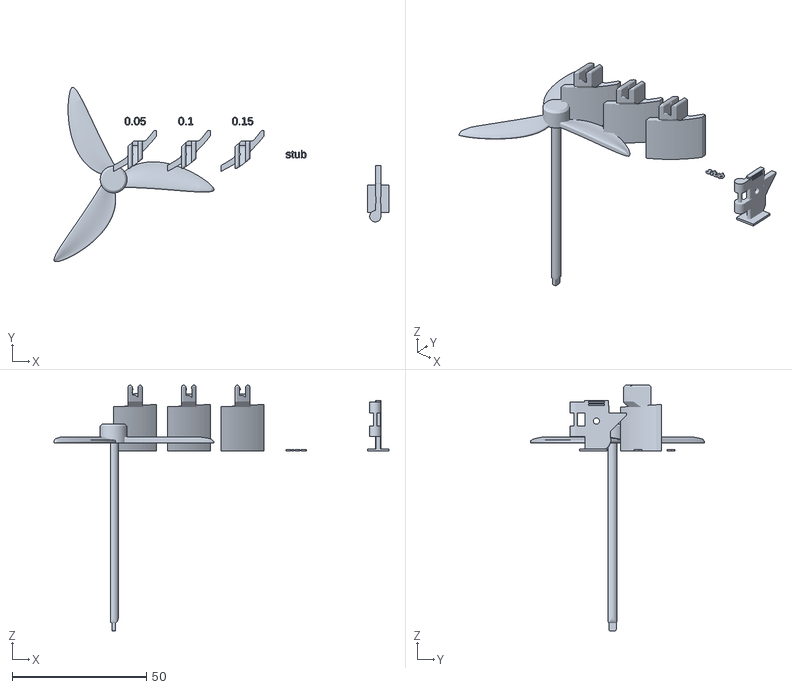
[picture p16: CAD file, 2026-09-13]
shroud/stl/saddle_coupon.stl
124.7 x 65.0 x 91.5

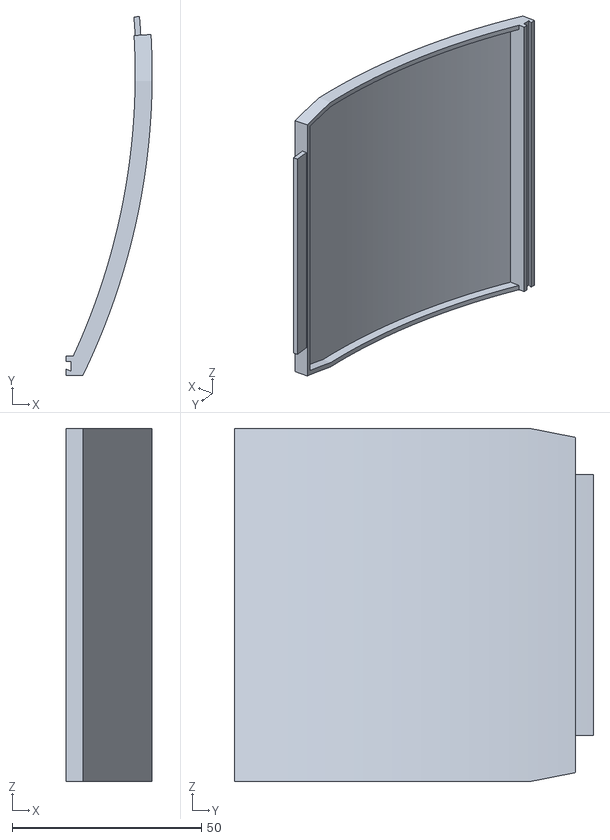
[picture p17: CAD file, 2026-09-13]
hatch/stl/hatch.stl
22.8 x 94.8 x 93.3

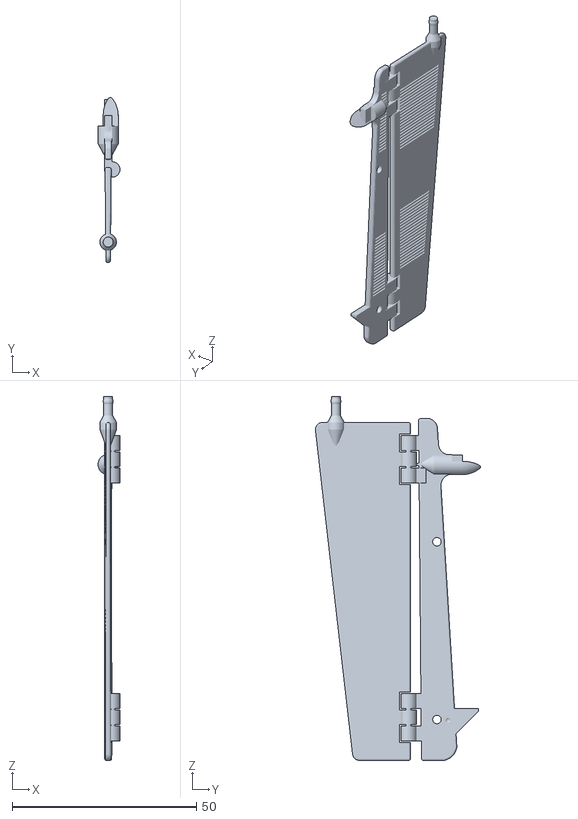
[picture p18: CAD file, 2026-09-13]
shroud/stl/vane_left_saddle.stl
5.95 x 44.8 x 98.7

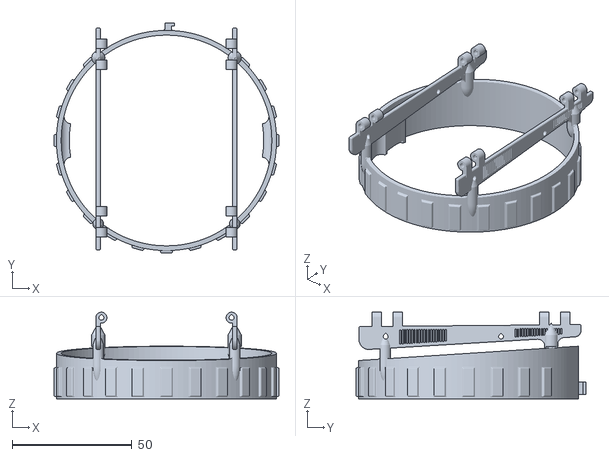
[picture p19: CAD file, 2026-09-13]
shroud/stl/shroud_fused.stl
94.0 x 96.1 x 36.2

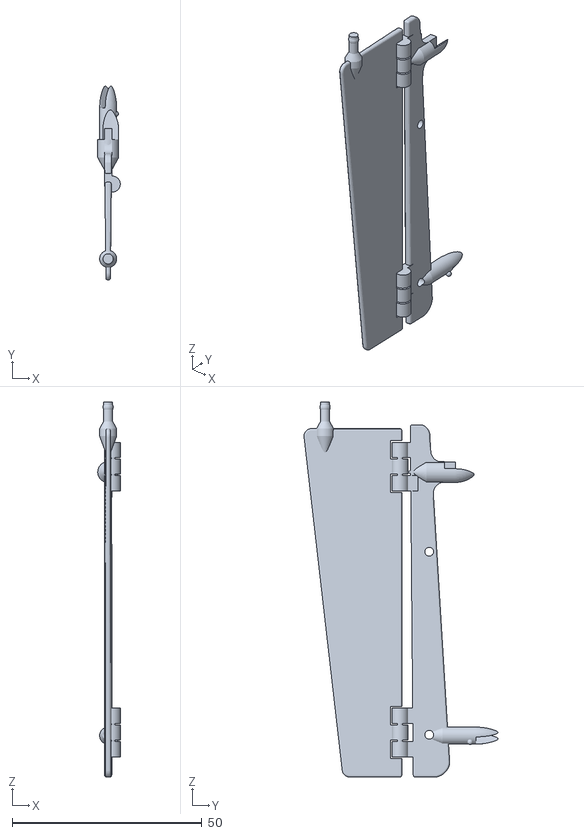
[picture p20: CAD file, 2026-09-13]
shroud/stl/vane_left.stl
5.95 x 51.1 x 98.7

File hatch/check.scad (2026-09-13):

// Collision checks. Each `pair` should be EMPTY (rail/groove and pin/hole have clearance).
//   pair: "hatch-front" | "front-mounts" | "hatch-mounts"
// Run: ../../tools/check.sh check.scad 'open_deg=0' 'open_deg=115'
include <whale_hatch.scad>
show_ghost = false; show_all = false; show_hull = false;
pair = "hatch-front";

module A() { rotate([-open_deg, 0, 0]) if (pair == "hatch-front" || pair == "hatch-mounts") hatch(); else front(); }
module B() { if (pair == "hatch-front") rotate([-open_deg, 0, 0]) front(); else mounts(); }
intersection() { A(); B(); }

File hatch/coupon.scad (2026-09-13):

// Tolerance coupon for the dovetail: three short socket blocks with the groove at three clearances,
// one 20 mm slice of the front plate's rail to try in each. Labels are the per-face clearance.
// Also three pin holes at three clearances for a spare pin stub.
include <whale_hatch.scad>
show_ghost = false; show_all = false; show_hull = false;

clrs = [0.1, 0.15, 0.25];
L = 20;
module label(t) { linear_extrude(0.6) text(t, size = 3, halign = "center"); }

// socket slices: the block profile (y across, z up) extruded straight up, so the groove is a
// vertical slot traced in every layer, like the real hatch printing on its side. Brim.
for (i = [0 : len(clrs) - 1]) translate([i * 16, 0, 0]) {
    linear_extrude(L) difference() {
        square([sock_d, sock_h]);
        translate([0, -seam_z]) polygon(rail_2d(clrs[i]));          // groove at this clearance
    }
    translate([sock_d / 2, -6, 0]) label(str(clrs[i]));
}
// rail slice: front plate 20 wide, 6 tall, rail on top; printed on its inner face like the real part
translate([-20, 0, front_t]) rotate([-90, 0, 0]) translate([0, 0, -seam_z + 6])
    intersection() { front_local(); translate([-10, -5, seam_z - 6]) cube([20, 20, 6 + rail_h + 1]); }
// pin holes at three clearances, for a printed pin stub
translate([0, 15, 0]) for (i = [0 : 2]) translate([i * 10, 0, 0]) difference() {
    cube([8, 8, mount_t]); translate([4, 4, -1]) cylinder(d = hinge_pin_d + [0.3, 0.4, 0.5][i], h = 6);
}
translate([-8, 19, hinge_pin_d / 2]) rotate([0, 90, 0]) cylinder(d = hinge_pin_d, h = 10);   // the pin stub, lying down

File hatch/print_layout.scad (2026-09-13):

// Print layouts: each part on the bed (z = 0) in its printing pose.
//   part = "hatch"  ON ITS SIDE (Armen 2026-09-11, for the smoothest outer face): the +X side face is
//                   the flat plane on the bed; arc, front face and dovetail groove are traced in every layer.
//                   93.3 tall. Brim.
//   part = "front"  flat on its INNER face: the rail's flat side and the pins lie on the bed, the
//                   dovetail taper is a top-side slope. Outer face up.
//   part = "mount"  flat on its glue face. Print two.
include <whale_hatch.scad>
show_ghost = false; show_all = false; show_hull = false;
part = "hatch";

if (part == "hatch") translate([0, 0, hatch_w / 2]) rotate([0, 90, 0]) hatch();     // x = +w/2 face -> z = 0
if (part == "front") translate([0, 0, front_t]) rotate([-90, 0, 0]) translate([0, 0, -front_bot]) front_local();
if (part == "mount") rotate([0, -90, 0]) mount_local();                              // x = 0 face -> z = 0

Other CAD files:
shroud/ref_bodies/vane_right.stl
shroud/stl/fin_left_fused.stl
shroud/stl/vane_right_filpin.stl
shroud/stl/vane_right.stl
hatch/whale_hatch.scad
shroud/Shroud.stl
shroud/check.scad
shroud/compare.scad
shroud/hinge_coupon.scad
shroud/print_layout.scad
shroud/saddle_coupon.scad
shroud/shroud.scad
shroud/shroud_makerworld.scad
shroud/stl/fan.stl
shroud/stl/hinge_coupon.stl
shroud/stl/hinge_coupon_filpin.stl
shroud/stl/shaft.stl
shroud/stl/shroud.stl
shroud/stl/shroud_saddle.stl
shroud/stl/slat.stl
shroud/stl/slat_fused.stl
shroud/stl/strut.3mf
shroud/stl/strut.stl
shroud/stl/tab_coupon.stl
shroud/stl/tie_bar.stl
shroud/stl/vane_left_filpin.stl
shroud/stl/vane_right_saddle.stl
shroud/stl/vane_right_saddle_filpin.stl
shroud/tab_coupon.scad

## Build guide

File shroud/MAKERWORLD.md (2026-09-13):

# G.I. Joe Killer W.H.A.L.E. Fan Shroud & Steering Vanes (1984)

A replacement fan shroud, steering vanes, and fan for the 1984 G.I. Joe Killer W.H.A.L.E. hovercraft. Designed from scratch in OpenSCAD using nothing but reference photos found online, test-fitted on my own extremely worn-out Whale. Fully open source.

## Why this exists

My brother and I had a Whale as kids (technically it was his, but we both loved it). It's one of the most iconic play-set vehicles ever made, and unfortunately one of the most brittle. The fan shrouds, vanes, and all the little bits broke off even back in the day. If yours looks like mine, this is the fix. Print two for a full set.

I also designed the Whale's cannon hatches, which people seem to like:
https://makerworld.com/en/models/690907-gi-joe-killer-whale-cannon-covers

## What makes this one different

- **Fully parametric CAD.** Written in OpenSCAD, so every tolerance (hinge clearance, strut fit, shaft fit) is a number at the top of the file. If your printer runs tight or loose, change one value and re-export instead of sanding. Use MakerWorld's Customize button: pick the part, tweak the clearances, generate.
- **Designed for PLA, not for the museum.** This is not a 100% faithful recreation. I took some liberties with the original so it prints at the best quality and strength. The vane roots and the shroud are one piece instead of separate snap-on parts, because that joint is where the original always broke.
- **Snap together, no glue.** The only extra thing you need is a few short lengths of 1.75 mm filament, which serve as the hinge pins for the vanes.

## Assembly

1. Print the shroud, the two vane plates, the slats, the tie bar, the strut, the fan, and the shaft.
2. Hinge the vanes: drop each vane plate between the knuckles on the shroud's vane roots, push a short piece of 1.75 mm filament through, trim it about 1 mm proud, and mushroom the ends with a lighter or soldering iron.
3. Slats ride on filament too: push a length through one root bar, through the slat, and out the other bar. Mushroom both ends.
4. Fit the tie bar across the vanes so they steer together.
5. Push the shaft into the socket under the fan hub and drop the fan into the shroud.
6. Lock in the strut last. It slides into the pockets inside the bore from the base side and holds the fan and shaft in place. The Whale's hull keeps it seated once the shroud is installed.

## Printing

- **Filament:** Bambu PLA Matte Dark Green.
- **Profile:** 0.16 mm High Quality on a Bambu.
- **Orientation matters.** Every part is oriented in the profile for the best combination of looks and strength. The vane plates stand on their long edge, the shaft lies on its flat, the shroud prints base down. If you reorient parts, some of them (the hinges and the thin vane features especially) will come out too brittle. Tread carefully.
- **Supports:** the shroud's root bars bridge the bore, so enable supports under them. The other parts print without support.

## Source

The OpenSCAD source is on GitHub (MIT): https://github.com/redswoop/gi-joe-killer-whale (the shroud is in `shroud/`). Tweak the tolerances, remix it, port it to another printer.

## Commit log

2026-09-10 WHALE fan shroud + vane mechanism, state as of 2026-09-09
    OpenSCAD port of the Shapr3D shroud plus the print-in-place vane set,
    harnesses (check, compare, print_layout, coupon), exported STLs, originals.
    Claude-Session: https://claude.ai/code/session_01NudZuaFsFjnData9fmkZEm
    [Shroud.step, Shroud.stl, check.scad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]
2026-09-10 Use shared lib/ helpers; check.scad lists strut pair; scripts filter NoError
    Generic modules (rounded_pad, wall_blend, arc_sweep, arc_pts, stroke_2d,
    grooves_2d, teardrop, keyhole) now come from ../lib via use<>. All seven
    STLs hash-identical to the pre-move export.
    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
    [check.scad, shroud.scad]
2026-09-11 tab_coupon: four lower-half shrouds with a ladder of hook slot widths; tab() takes a grip argument
    Claude-Session: https://claude.ai/code/session_017k7B2rq7WsgRiHJi17frUf
    [hinge_coupon.stl, shroud.scad, tab_coupon.scad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]
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2026-09-11 Strut mount v4: dovetail slides (boss + slot on the bore wall, chamfered tails on the bar); coupon carries three tail clearances
    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
    [check.scad, hinge_coupon.scad, hinge_coupon.stl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]
2026-09-11 Strut mount v4: curved ears on the bar slide up into blind pockets in the bore wall from the base side
    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
    [check.scad, hinge_coupon.scad, hinge_coupon.stl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]
2026-09-11 Strut bosses fade into the bore wall: 3 mm concave fillets on sides and top via offset(+f)/offset(-f)
    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
    [hinge_coupon.stl, shroud.scad, shroud.stl]
2026-09-11 tab_grip = 0.7 from the tab coupon (0.8 best but tight, 0.5 loose)
    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
    [shroud.scad, shroud.stl, strut.3mf]
2026-09-11 Tab: tab_stem_extra widens the stem toward the foot; tab coupon round 2 ladders it at grip 0.7
    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
    [shroud.scad, tab_coupon.scad, tab_coupon.stl]
2026-09-11 tab_stem_extra = 0.2 from tab coupon round 2 (0.15 and 0.3 good, 0.3 a tad much)
    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
    [shroud.scad, shroud.stl]
2026-09-11 hinge_clr 0.4 -> 0.3: printed vanes too loose; coupon ladders 0.25/0.30/0.35
    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
    [hinge_coupon.scad, hinge_coupon.stl, shroud.scad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]
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2026-09-11 Fork teeth straddle the rim; hinge_clr 0.15, slat_clr 0.15, slats span the bars; coupon ladders all three
    Vane-to-shroud: the drop-in pegs sat loose and rocked. Each tooth is now a fork in the bar's plane: a key that drops 3 mm into a rim notch (locates along the rim, Z stop) and two prongs reaching 7 mm down both faces of the wall. The slot is the wall's annulus offset tooth_clr, so it follows the curve where the bar crosses the ring obliquely. Slot mouth chamfered; click nub moved onto the key.
    hinge_clr 0.3 -> 0.15 and slat_clr 0.2 -> 0.15 per Armen's tolerance tests; the slat plate now spans the bars less 0.3 mm end gaps instead of stopping 1.5 mm short.
    hinge_coupon: hinge 0.15/0.20/0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
    [hinge_coupon.scad, hinge_coupon.stl, shroud.scad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]
2026-09-11 Fork teeth become darts: filleted sides converging to a round nose, inside face thinned toward the tip
    Armen: 'taper the teeth so they swoop into the duct, slightly conical, like the lights on an art-deco wing'. tooth_dart_2d hulls an 11 mm top buried in the bar to a 3.5 mm nose circle; tooth_profile_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
    [hinge_coupon.scad, hinge_coupon.stl, shroud.scad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]
2026-09-11 Fork teeth become canoe-fairing pods: bullet about a Z axis, D-clipped at the outer face, round rim notch
    Armen rejected the flat dart ('not bad, but ugly') with a reference to flap-track fairings. The tooth is now a body of revolution along the airflow: elliptical nose into the duct, cylinder through th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
    [hinge_coupon.scad, hinge_coupon.stl, shroud.scad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]
2026-09-11 Dart teeth: 8 mm elliptical nose reaching 11 below the rim; bar and plate edges rounded 0.7
    Armen: 'lets go with a dart, that extends towards the middle of the shroud and tapers' -> tooth_nose 3 -> 8, tooth_prong 7 -> 11 (the -Y tip lands at z 5.6, the +Y at 10.3). 'fillet all of the edges of the vanes, they look too blocky' -> plate_yz() builds the bar and the plate with rounded_plate() (new in lib/shape.scad), vane_edge_r = 0.7 on both faces. Coupon tooth stubs respaced for the longer dart. All collision pairs clear.
    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
    [hinge_coupon.scad, hinge_coupon.stl, shroud.scad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]
2026-09-11 +Y teeth back to the sketch peg (base slot); -Y fork dart round, slender (r 2.25, ogive), keep-out for the deco boxes; vanes print standing
    Armen: the bottom tabs drop into a slot in the Whale's base, so they keep the original size, depth and sharp edges: peg() is Sketch 06's rectangle, rim slot as before. The flat-clipped pod 'looks wei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
    [hinge_coupon.scad, hinge_coupon.stl, print_layout.scad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]
2026-09-11 Vanes taper 2.0 -> 1.2 from the bar's root to the plate's tip, symmetric; plate's -Y inner corner squared; link pin on the mid-plane with an unclipped bullet root
    Armen: 'the slightest taper ... widest at the root where they attach to the duct ... thin edge at the outside; make sure the linkage bar mounts don't end up floating', and the plate's top inner corner should be square like the bar's. plate_yz() now intersects the shrunk outline with thk_wedge() before the sphere minkowski (vane_edge_r 0.7 -> 0.5 so the tip can be 1.2); face_cut() measures groove depth from the sloping face via outer_beyond(). pin_x = mid-plane; the bullet root wraps the corner on both faces. All collision pairs cle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
    [shroud.scad, tie_bar.stl, vane_left.stl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]
2026-09-11 Link pin mounts canoe up the plate, 3 mm in from the edge; tie bar's raised middle flush with the plate's outer edge
    Armen (with a screenshot of the pegs): 'these should also canoe up the vane', 'move them downward about 3 mm so they aren't at the edge', 'the top of the /----\ and the edge of the vane should be flush'. The root is a body of revolution about the pin's axis (tail cone up the plate, cylinder, nose cone to the pin), mount_d 4.5 like the tooth; link_pin_inset 2.8 -> 5.8; tie_jog derived as link_pin_inset - tie_w / 2 so the hat's top lands on the plate edge (tie bar STL spans exactly to z 59.2). All collision pairs clear at all poses.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
    [shroud.scad, tie_bar.stl, vane_left.stl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]
2026-09-11 Plate's +Y inner corner squared too, to match the bar's end corner
    Armen: 'when you squared the top corner of the outer vane, you didn't do the bottom edge.' Both inner corners along the hinge are square now; the outer corners keep fin_corner.
    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
    [shroud.scad, vane_left.stl, vane_right.stl]
2026-09-11 Fork dart stays full round 1.5 past the bar's bottom edge before its tail cone starts
    Armen: the cone met the bar's edge 'as a single point, feels like a failure point'. tooth_over replaces tooth_tail0: the pod straddles the edge at full diameter and the tail fades out on the bar's face (through the slat hole, where it is barely proud). Collision pairs clear.
    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
    [hinge_coupon.stl, shroud.scad, vane_left.stl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]
2026-09-11 README: hinge_clr 0.15 confirmed on a printed vane ('almost feels oiled'); fork darts broke during support removal
    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
2026-09-11 Saddle-mount alternative for the vanes' -Y end (ny_mount = "fork" | "saddle")
    The fork darts broke off during support removal. In the saddle variant the
    shroud grabs the vane: a block on the rim at each -Y crossing, printed flat
    with the shroud, has a channel the bar drops into (cheeks to 24.5, lead-in)
    and a pocket for the sketch's -Y peg, now a 45 deg wedge so the standing vane
    prints it without support. Nub on the inner cheek, dimple in the bar. Fades
    and 45 deg chamfers below the rim, clear of the deco boxes and the slat rod.
    Fork geometry is unchanged by the switch (voxcmp 0). All collision pairs
    clear at every pose. saddle_coupon.scad ladders chan_clr 0.05/0.10/0.15;
    export.sh writes t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
    [hinge_coupon.stl, saddle_coupon.scad, saddle_coupon.stl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]
2026-09-11 Filament hinge pin as a switch (hinge_pin = "printed" | "filament")
    The standing vane print was beautiful but the print-in-place pins, a stack
    of 1.4 mm discs held by layer adhesion, snapped when the plates were freed.
    In filament mode the knuckles get a plain 2.05 hole straight through the nub
    for a 1.75 filament pin (barrel 4.6, 1.28 walls; hinge line +0.2), no
    teardrop, root and plate still printed together in place. hinge_coupon
    ladders fil_clr 0.10/0.15/0.20 in that mode. export.sh now runs in
    parallel and writes _filpin and _saddle_filpin vanes beside the others.
    Defaults unchanged (vane volume identical); collision table clear for
    every combination.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
    [hinge_coupon.scad, hinge_coupon_filpin.stl, saddle_coupon.stl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]
2026-09-11 tooth_clr 0.15 -> 0.10: coupon round 3, the 0.10 fork dart was the best fit on the rim
    Claude-Session: https://claude.ai/code/session_01WNZRLqMdPCnjpqaDWMxDYS
    [saddle_coupon.stl, shroud.scad, vane_left.stl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]
2026-09-11 fil_clr 0.15 confirmed: middle sample of the filament hinge coupon was the best fit
    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
    [shroud.scad]
2026-09-11 Re-export all STLs for the full test print (fil_clr 0.15, tooth_clr 0.10)
    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
    [saddle_coupon.stl, vane_left.stl, vane_left_filpin.stl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]
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2026-09-11 Parametric skeleton: arc plate through hinge/top edge with sagitta, corner hinge eyes, bay mock, open_deg; photo readings in README
    [print_layout.scad, whale_hatch.scad]
2026-09-12 Plate profile from Armen's tracing: 90 long, hinge end 18 below the flat end, sagitta 5.9 (R 180.7)
    [whale_hatch.scad]
2026-09-12 hatch_t 1.5 (shell thickness); README: hatch is missing, profile traced off the fender edge
    [whale_hatch.scad]
2026-09-12 Shape-check STL: 45 deg bevel at the cabin end, hinge_style switch (none for now), standing print pose on the hinge end face
    [hatch.stl, print_layout.scad, whale_hatch.scad]
2026-09-12 Tray with rim, hinge bar with ears and outward pins, cabin_tuck, plan corner chamfers; print pose on the cabin end. From eBay photos of M-3798-4
    [hatch.stl, print_layout.scad, whale_hatch.scad]
2026-09-12 Slide-on hinge bar: dovetail tongue on the hatch, flat-printed channel with pins; hatch prints on its side; hatch-bar collision check clear
    [bar.stl, check.scad, hatch.stl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]
2026-09-12 Cabin end: 45 deg corners to the 68.85 top-hatch opening width; stepped ledge (2.7 down, 1.5 thick, 5 reach) under the top hatch; bar lip param renamed
    [hatch.stl, whale_hatch.scad]
2026-09-12 Hinge end: 90 deg flange (5 x 1.5) with the dovetail tongue on its free edge; slide bar moves to the flange tip; rims trimmed for the bar; hatch-bar clear
    [bar.stl, hatch.stl, print_layout.scad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]
2026-09-12 Fused variant (vane_mount = "fused"): root bars part of the shroud, plates and slats on filament pins
    Armen's idea: combine the shroud and the vane roots into one strong print. Each bar stands on a
    post() at both wall crossings (the bar's slab trimmed to the annulus, filleted foot); no notches,
    teeth, pegs or receivers. Plates become separate parts on the filament hinge (hinge_pin_eff forces
    "filament"; root holes are teardrops since they print lying down). Slats get a barrel and a
    filament axle pushed in from outside the bars. print_layout: fin_right / fin_left parts, shroud
    carries the roots when fused. export.sh: _fused STLs. check.scad: roots-duct skipped when fused.
    Fused collision tabl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
    [check.scad, fin_left_fused.stl, fin_right_fused.stl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]
2026-09-12 Fused plates print standing on their long outer edge, knuckles up (fin_print = "edge"); hinge hole becomes a teardrop
    Armen's print experiments: standing the plate on the edge opposite the hinge gives the best result.
    print_layout levels the trapezoid's slanted edge (fin_slant) and sets it on the bed; the plate's
    filament hole now prints horizontal, so fil_hole() takes roof = -1 (point toward the hinge side, up
    on the printer). fin_print = "vertical" keeps the old pose.
    Claude-Session: https://claude.ai/code/session_01W6pfx78FsmspXtCJ14FvPq
    [fin_left_fused.stl, fin_right_fused.stl, print_layout.scad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]
2026-09-12 Fan and shaft: parametric replacement for the web mesh (wedge blades print flat, D shaft prints on its flat)
    Measured from GI_Joe_Killer_Whale_Blade.stl: 3 blades, tip r 42.6, ~16 deg pitch, straight trailing
    edge + swept leading edge, 3.5 mm shaft, 1.6 x 1.2 tab. fan(): hub with a blind D socket, blades as
    polyhedra with the reference planform and an elliptical tip, wedge section (flat bottom, blade_pitch
    top) so the fan prints flat with no support. Tip follows the strut boss (boss_r_in - fan_tip_clr =
    39.6): the reference's 42.6 hits the bosses. shaft(): D rod, shaft_reach 65 + shaft_extra (TBD),
    tab on the tip; prints lying on the flat. check.scad: fan-duct, fan-strut, fan-roots, shaft-st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
    [check.scad, fan.stl, print_layout.scad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]
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2026-09-12 Shaft tip is a keyed blade with rounded shoulders (the gear's socket has a keyed slot and sloped walls)
    Armen got the gear out of the hull: a boss with a sloped socket and a keyed slot in its floor.
    shaft_tip(): blade tab_w x tab_t x tab_len (placeholders) with rounded end corners, convex
    quarter-ellipse shoulders tab_ramp long from the shank's round to the blade in both directions
    ('rounded ramps to meet with the ramps in the socket'), the D flat carried through. Replaces
    the mesh's guessed pin.
    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
    [print_layout.scad, shaft.stl, shroud.scad]
2026-09-12 +Y peg root flared into the bar with 3 mm concave fillets (the printed vane snapped off at the root)
    Armen 2026-09-12: 'the vane root snapped off the duct. the mounting posts were just too small... a filleted edge on the top; we can make the connection point taller, we have some clearance.' peg_2d() = offset(+f)/offset(-f) on bar + peg, boxed to the peg, so the 2 x 5.27 root becomes an 11 mm wide flare in the bar's plane, stopping ~1 mm above the rim; the peg below the rim is untouched (base slot). Full 2 mm thick. All 14 collision pairs clear.
    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
    [fin_left_fused.stl, fin_right_fused.stl, hinge_coupon.stl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]
2026-09-12 +Y peg wrapped in a canoe: full pod above the rim with a tail up the bar, half-canoe with an ogive nose down the bore wall below it
    Armen 2026-09-12: 'a bit of a canoe around that bottom connection as well, just the upper half of it, so it doesn't collide with that cut', then 'a half-canoe on the inner surface of the duct too'. peg_pod(): revolve r 2.75 about the peg's centre line; below 0.5 above the rim everything outside r = duct_r_in - tooth_clr is cut away, leaving an inner prong reaching 8 below the rim. Added after the groove cuts so the tail is smooth over the panel. All collision pairs clear, fan included.
    Claude-Session: htt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
    [fin_left_fused.stl, fin_right_fused.stl, saddle_coupon.stl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]
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2026-09-13 shroud: MakerWorld customizer build (shroud_makerworld.scad via build_makerworld.py); fix tooth_clr_eff ordering; re-export STLs
    MakerWorld's Parametric Model Maker takes one file and runs OpenSCAD 2021.01, so the uploaded shroud.scad
    lost every lib module (no vane ribs, no tie bar, no rim details). build_makerworld.py inlines ../lib, adds a
    part selector and a curated parameter set; every part renders with the same volume/area/bbox as print_layout.scad.
    tooth_clr_eff / tooth_lead_eff were assigned before tooth_clr / tooth_lead existed (undef in the teeth variant since
    2026-09-12); moved after the tooth block. export.sh re-run: teeth vane STLs change, fused STLs were stale.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
    [fin_left_fused.stl, fin_right_fused.stl, saddle_coupon.stl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]
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2026-09-13 hatch: dovetail doubled after coupon round 1 (rail 2.5/1.8/1.2, front 4.0, socket 5.5), coupon round 2 at -0.1/0/0.1; pin_clr 0.3 settled and moved to lib/fit.scad known H2C clearances; re-export
    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
2026-09-13 windscreen: three flat clear panels + tabbed base, from Armen's dimensions
    Panels defined by 3D corner points; flat outline and placement derive from them.
    60/54 back, 40/44 sides, 10 tall, 1 mm PETG; base rail with tilted grooves and
    three 5x5x2 deck tabs. Collision pairs clear. Coupon unprinted.
    Claude-Session: https://claude.ai/code/session_019u4cJgqTGhFkhcutNiHrHi
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2026-09-14 hatch: front replicates the real ramp's front band (pin_below_lip 8, half-round bottom edge coaxial with the pins); brackets re-homed to the skirt's broken boss stubs; note a2 done
    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
2026-09-14 hatch: hull-side hinge as a captured C-clip over the middle layer's front edge
    Armen took the hull apart: the original hinge was two thin panels under the
    middle layer, snapped off; nothing to glue to, no drilling. The bracket is
    now a C-clip (lip on top, bridge in the 2 mm recess, slotted leg underneath,
    pin boss off the bridge) captured by the layer and tied together by the
    ramp's pins. Nose mock + three new check pairs; export makes three grips.
    Axis moved 0.75 forward for the hole's back wall. open_deg rotated the wrong
    way (cabin end down through the bay); fixed, checks sweep 0..180.
    Teardown photos in ref/hull_apart_0..9.
    Claude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
2026-09-14 hatch: rail_shrink 0.1 on the front's dovetail rail (first print too tight), groove untouched
    Claude-Session: https://claude.ai/code/session_01DiNJ1qJGbymYQGnRvqCQUC
